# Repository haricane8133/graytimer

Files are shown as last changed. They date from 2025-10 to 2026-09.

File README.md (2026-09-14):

# E-Paper Watch

* A fully customizable, ePaper, battery-optimized smartwatch.
* Auto shuffles between available watchfaces every 10 mins.
* Make this if you want to build/solder every component rather than building on a compact PCB.

<table>
  <tr>
    <td align="center" width="45%">
      <br/>
      <b>Full refresh</b>
    </td>
    <td align="center" width="45%">
      <br/>
      <b>Partial Refresh</b>
    </td>
  </tr>
</table>

[Gallery (includes all watchfaces)!](docs/GALLERY.md)

---

## Quick Start

### Hardware Requirements

- **MCU**: Seeed Xiao nRF52840
- **Display**: GoodDisplay 1.54" (GDEH0154D67)
- **RTC**: DS3231 with backup battery
- **Battery**: LiPo 3.7V (300-500mAh recommended)

**[📋 Detailed Hardware Guide →](docs/HARDWARE.md)**

### Software Setup

1. **Install Arduino IDE** (v1.8.x or v2.x)

2. **Add Seeed nRF52 Board Support**
   - Preferences → Additional Board URLs
   - Add: `https://files.seeedstudio.com/arduino/package_seeeduino_boards_index.json`
   - Tools → Board → Boards Manager → Search "Seeed nRF52" → Install
   - Initially had the idea of using NFC for changing watchface and setting time. So this micro controller was chosen. But we later found out that NFC tag type 4, which is required for receiving NDEF NFC records weren't supported by the arduino libraries.

3. **Install Required Libraries** (via Library Manager)
   - GxEPD2 by Jean-Marc Zingg
   - Adafruit GFX Library
   - RTClib by Adafruit

**[📖 Complete API Reference →](docs/API.md)**

### Hardware

The `/hardware` folder contains the designs to 3D print for the watch case

---

## Project Structure

```
epaper_watch/
├── epaper_watch.ino        # Main sketch
├── myutils.h               # Headers and includes
├── myutils.cpp             # Display rendering logic
├── WatchFace.h             # WatchFace class definition
├── RTCManager.h            # Time management
│
├── myfonts/                # Custom GFX fonts (66 fonts)
├── mywatchfaces/           # Watchface definitions (95 watchfaces)
│
├── watchfaceutils/         # Python development tools
│   ├── configure_watchface.py
│   ├── render_watchface.py
│   └── generate_all_previews.py
│
└── docs/                   # Documentation
    ├── README.md           # Documentation index
    ├── GALLERY.md          # All watchfaces with previews
    ├── API.md              # WatchFace API reference
    └── HARDWARE.md         # Detailed hardware guide
```

---

## 📚 Full Documentation

For detailed information including configuration, troubleshooting, development tools, and more:

**[→ Read the complete documentation in the /docs folder](docs/README.md)**

---

Thanks to @vu2ow for helping out!

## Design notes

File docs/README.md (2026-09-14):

# E-Paper Watch Documentation

Complete documentation for the e-paper watch project.

---

## Documentation Index

- **[Watchface Gallery](GALLERY.md)** - Browse all 95 watchfaces with preview images
- **[WatchFace API Reference](API.md)** - Complete API documentation for creating custom watchfaces
- **[Hardware Guide](HARDWARE.md)** - Detailed hardware specifications, wiring, and assembly

---

## Features

- **Display**: 200×200 monochrome e-paper (1.54", 200 DPI)
- **Watchfaces**: 95+ pre-configured with custom fonts
- **Time Keeping**: DS3231 RTC (±2 minutes/year accuracy)
- **Refresh Modes**: Partial (fast) and full (ghosting-free)
- **Development Tools**: Python scripts for creating custom watchfaces

---

## Configuration

### Main Settings

Edit `epaper_watch.ino` to customize behavior:

```cpp
// Enable/disable features
const bool ENABLE_WATCHFACE_CYCLING = true;  // Auto-cycle every 10 mins
const bool ENABLE_PARTIAL_REFRESH = true;    // Fast updates
const bool ENABLE_SERIAL_DEBUG = false;      // Disable for battery life

// Timing
const uint8_t FULL_REFRESH_INTERVAL = 10;    // Minutes (10 = :00, :10, :20...)
const uint8_t WAKE_BEFORE_MINUTE_SEC = 57;   // Wake at :57s (3s poll window)
const uint16_t POLL_INTERVAL_MS = 200;       // Poll every 200ms
```

### Power Optimization

**Maximum Battery Life**:
```cpp
const uint8_t WAKE_BEFORE_MINUTE_SEC = 50;  // 10-second window
const uint16_t POLL_INTERVAL_MS = 300;       // Poll every 300ms
const bool ENABLE_SERIAL_DEBUG = false;      // Disable serial
```

**Balanced** - **Default**:
```cpp
const uint8_t WAKE_BEFORE_MINUTE_SEC = 57;  // 3-second window
const uint16_t POLL_INTERVAL_MS = 200;       // Poll every 200ms
const bool ENABLE_SERIAL_DEBUG = false;      // Disable serial
```

**Fast Response**:
```cpp
const uint8_t WAKE_BEFORE_MINUTE_SEC = 59;  // 1-second window
const uint16_t POLL_INTERVAL_MS = 100;       // Poll every 100ms
```

---

## Creating Custom Watchfaces

### Using Python Tools (Recommended)

```bash
cd watchfaceutils

# Interactive configurator with live preview
python3 configure_watchface.py

# Test single watchface
python3 render_watchface.py \
  --watchface ../mywatchfaces/custom.h \
  --time-font ../myfonts/Font20pt7b.h \
  --date-font ../myfonts/Font10pt7b.h \
  --output custom_preview.png

# Generate all previews
python3 generate_all_previews.py
```

### Manual Configuration

**Step 1**: Prepare 200×200 monochrome image

**Step 2**: Convert to bitmap array using [image2cpp](https://javl.github.io/image2cpp/)

**Step 3**: Create watchface header file

```cpp
// mywatchfaces/custom.h
const unsigned char custom_bitmap[] PROGMEM = {
  // ... bitmap data ...
};

// Required array wrapper
static const int custom_bitmap_allArray_LEN = 1;
static const unsigned char* custom_bitmap_allArray[1] = {
  custom_bitmap
};

// WatchFace class
struct WatchFace_custom : public WatchFace {
  WatchFace_custom() {
    bitmap = custom_bitmap;
    layout = 1;              // 0=single-line, 1=two-line

    // Time positioning
    text1x = -1;             // -1=center, 0-100=percentage
    text1y = 40;             // 40% from top
    text1font = &Font20pt7b;

    // Date positioning
    text2x = -1;
    text2y = 60;             // 60% from top
    text2font = &Font10pt7b;
  }
};
```

**Step 4**: Include in `myutils.h`
```cpp
#include "mywatchfaces/custom.h"
```

**Step 5**: Add to `epaper_watch.ino`
```cpp
WatchFace* allWatchFaces[] = {
  // ... existing watchfaces ...
  new WatchFace_custom(),
};
```

**[📖 Complete API Reference →](API.md)**

---

## Watchface Gallery

**[📸 View All 95 Watchfaces →](GALLERY.md)**

Preview of available watchfaces:

<table>
  <tr>
    <td align="center">
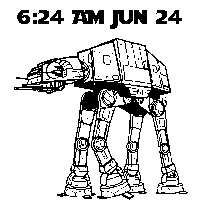
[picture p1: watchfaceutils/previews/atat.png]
      <br/>
      <b>AT-AT</b>
    </td>
    <td align="center">
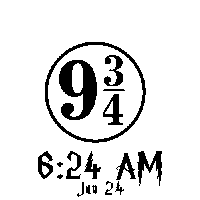
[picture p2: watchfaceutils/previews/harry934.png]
      <br/>
      <b>Harry Potter</b>
    </td>
    <td align="center">
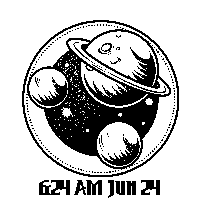
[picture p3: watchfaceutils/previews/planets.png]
      <br/>
      <b>Planets</b>
    </td>
  </tr>
  <tr>
    <td align="center">
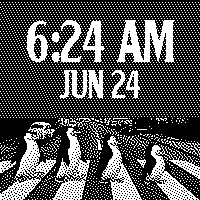
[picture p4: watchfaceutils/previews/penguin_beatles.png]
      <br/>
      <b>Beatles Penguins</b>
    </td>
    <td align="center">
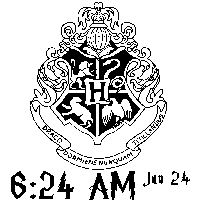
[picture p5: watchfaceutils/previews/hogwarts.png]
      <br/>
      <b>Hogwarts</b>
    </td>
    <td align="center">
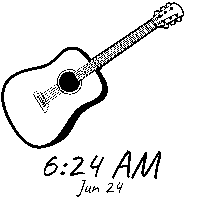
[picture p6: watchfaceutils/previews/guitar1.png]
      <br/>
      <b>Guitar</b>
    </td>
  </tr>
</table>

**Collections**: Star Wars (13) • Harry Potter (10) • Club Penguin (8) • Animals (9) • Other Characters (11) • Horizon Zero Dawn (6) • Music & Entertainment (8) • Nature & Landscapes (9) • Space (7) • Cultural & Spiritual (6) • Everyday Things (3) • Abstract & Patterns (5)

---

## Troubleshooting

### Display Issues

**Display not updating**
- Check SPI connections (DAT/MOSI→D10, SCL/SCK→D8, CS→D1, DC→D3, RES→D0, GND) — full pinout in [HARDWARE.md](HARDWARE.md)
- Verify 3.3V power supply
- Run the standalone diagnostic `hardware/epd_test/epd_test.ino` (BUSY on D9)
- Try disabling partial refresh: `const bool ENABLE_PARTIAL_REFRESH = false;`

**Display is garbled**
- Verify correct model (GDEH0154D67)
- Check ground connection
- Ensure proper SPI wiring

**Ghosting artifacts**
- Increase full refresh frequency: `const uint8_t FULL_REFRESH_INTERVAL = 5;`
- Temperature affects ghosting (worse in cold)

### RTC Issues

**Time is incorrect after upload**
- Enable time setup: `const bool ENABLE_TIME_SETUP = true;`
- Upload and open Serial Monitor (115200 baud)
- Follow prompts to set time

**RTC not detected**
- Verify I2C connections (SDA, SCL)
- Check I2C address (0x68)
- Test with I2C scanner
- Try different RTC module

### Power Issues

**Battery drains too quickly**
1. Disable serial debug: `const bool ENABLE_SERIAL_DEBUG = false;`
2. Optimize wake time: `const uint8_t WAKE_BEFORE_MINUTE_SEC = 50;`
3. Check for shorts or bad connections
4. Measure current with multimeter

**Time updates miss minute changes**
1. Increase polling window: `const uint8_t WAKE_BEFORE_MINUTE_SEC = 55;`
2. Decrease poll interval: `const uint16_t POLL_INTERVAL_MS = 100;`

### Compilation Errors

**"library not found"**
- Install missing library via Library Manager

**"multiple definition"**
- Ensure bitmap arrays in watchface files have `static` keyword:
  ```cpp
  static const unsigned char* bitmap_allArray[1] = { ... };
  ```

**"struct redefinition"**
- Check for duplicate struct names
- Ensure watchface files included only once

---

## Performance Metrics

### Memory Usage

```
Flash (1MB total):        ~800KB used (78%)
  - Sketch:               ~85KB
  - Libraries:            ~68KB
  - Fonts (66):           ~380KB
  - Watchfaces (70):      ~350KB

RAM (256KB total):        ~23KB used (9%)
  - Global variables:     ~12KB
  - Display buffer:       ~5KB
  - Stack:                ~4KB
```

### Power Consumption

| Mode | Current | Notes |
|---|---|---|
| Deep Sleep | ~50µA | Between polling windows |
| Active Polling | ~1mA | Last 3 seconds of each minute |
| Display Partial | ~5mA | 200-500ms duration |
| Display Full | ~8mA | 1-2s duration every 10 mins |
| **Average** | **200-500µA** | Typical usage |

### Timing

| Operation | Duration |
|---|---|
| Partial refresh | 200-500ms |
| Full refresh | 1-2s |
| Text rendering | 50-100ms |
| Bitmap drawing | 100-200ms |
| RTC read | <1ms |

---

## Adding/Removing Watchfaces

### Add a Watchface

1. Create header file in `mywatchfaces/`
2. Include in `myutils.h`:
   ```cpp
   #include "mywatchfaces/your_watchface.h"
   ```
3. Add to array in `epaper_watch.ino`:
   ```cpp
   WatchFace* allWatchFaces[] = {
     // ... existing ...
     new WatchFace_your_watchface(),
   };
   ```

### Remove a Watchface

1. Comment out in `epaper_watch.ino`:
   ```cpp
   // new WatchFace_unused(),
   ```
2. Optionally comment out include in `myutils.h` to save memory

---

## Development Tools

### Python Scripts

**`configure_watchface.py`**: Interactive step-by-step configurator
- Select watchface and fonts
- Position text interactively
- Generate C++ code
- Save configuration

**`render_watchface.py`**: Command-line renderer for testing
- Render single watchface
- Test different positions
- Generate preview images

**`generate_all_previews.py`**: Batch preview generator
- Generate all watchface previews
- Auto-detects configurations
- Useful for documentation

### Python Requirements

```bash
pip3 install Pillow
```

---

## Technical Specifications

| Specification | Details |
|---|---|
| **MCU** | Nordic nRF52840 (ARM Cortex-M4, 64MHz, 1MB Flash, 256KB RAM) |
| **Display** | GoodDisplay GDEH0154D67 (1.54", 200×200, SPI, E-Ink) |
| **RTC** | Maxim DS3231 (I2C, TCXO, ±3.5ppm) |
| **Power** | 3.7V LiPo, 300-500mAh recommended |
| **Update Latency** | <3 seconds during watch face refresh |
| **Refresh Rate** | Partial updates every minute, full every 10 minutes |

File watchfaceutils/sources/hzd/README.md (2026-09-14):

Floyd-Steinberg dithered (1-bit, at final on-screen size) conversions of the machine renders
from the Horizon Wiki (https://horizon.fandom.com, files `<Machine>-Render.png`), background
and ground shadow removed via the alpha channel. Sized exactly for their boxes in
`generate_geometric.py` (dither patterns must not be resampled).

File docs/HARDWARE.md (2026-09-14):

# Hardware Reference

Detailed hardware information for the e-paper watch project.

---

## Bill of Materials

| Component | Specification | Notes |
|---|---|---|
| MCU | Seeed Xiao nRF52840 Sense | Nordic nRF52840, 64MHz, 1MB Flash, 256KB RAM, BLE 5.0 |
| Display | GoodDisplay GDEH0154D67 | 1.54", 200×200, SPI, partial refresh capable |
| RTC | DS3231 Module | I2C, ±3.5ppm, integrated TCXO, backup battery |
| Battery | LiPo 3.7V | Recommend 300-500mAh, JST connector |
| Button | Tactile switch (optional) | For future features |

---

## Pin Connections

### E-Paper Display (SPI)

Breakout boards label the same two SPI lines differently; all names in the
"EPD Pin" column are equivalent.

```
MCU Pin     | Function      | EPD Pin            | Description
------------|---------------|--------------------|---------------------------
D10 (P1.11) | SPI MOSI      | DAT / DIN / SDA    | Data from MCU to display
D8  (P1.13) | SPI SCK       | SCL / CLK / SCK    | SPI clock signal
D1  (P0.02) | GPIO (CS)     | CS                 | Chip select (active low)
D3  (P0.29) | GPIO (DC)     | DC                 | Data/Command selection
D0  (P0.26) | GPIO (RST)    | RES / RST          | Reset (active low)
D9  (P1.12) | GPIO (BUSY)   | BUSY               | Busy signal from display (see note)
            | Power         | VCC / 3V3          | 3.3V from MCU (not 5V)
            | Ground        | GND                | Common ground
```

**BUSY note**: the firmware passes `-1` for BUSY and uses fixed delays instead
(`myutils.cpp`), so the display works with only the five signal wires plus power.
BUSY is still wired to **D9** because the diagnostic sketch in
[`hardware/epd_test/`](../hardware/epd_test/epd_test.ino) needs it, and it can be
enabled in the firmware by replacing the `-1` with `EPD_BUSY`. BUSY used to be on
D6; that pin is now buried under epoxy on the Xiao and should be treated as
unavailable. If the display breakout has a MISO/SDO pin, leave it unconnected.

### RTC (I2C)

```
MCU Pin     | Function      | RTC Pin  | Description
------------|---------------|----------|---------------------------
D4  (P0.04) | I2C SDA       | SDA      | I2C data line
D5  (P0.05) | I2C SCL       | SCL      | I2C clock line
D2  (P1.10) | GPIO (INT)    | SQW/INT  | Optional: interrupt/alarm
            | Power         | VCC      | 3.3V from MCU
            | Ground        | GND      | Common ground
```

**Note**: RTC module should have backup coin cell battery (CR2032) for timekeeping during power loss.

### Optional Peripherals

```
MCU Pin     | Function      | Purpose
------------|---------------|--------------------------------
D7  (P1.15) | GPIO (Button) | User input (future features)
D2  (P1.10) | GPIO (INT)    | RTC SQW/INT (defined, unused)
```

Free / unavailable pins: **D6** (P1.14) is under epoxy — do not plan on it.
Every other Xiao pin is assigned above.

---

## Power Distribution

```
┌──────────────┐
│   LiPo       │
│   Battery    │
│   3.7V       │
└──────┬───────┘
       │
       ├─────────► nRF52840 (onboard regulator → 3.3V)
       │                │
       │                ├─────────► E-Paper Display (3.3V)
       │                ├─────────► DS3231 RTC (3.3V)
       │                └─────────► Peripherals
       │
       └─────────► Charging Circuit (USB-C on Xiao)
```

---

## Electrical Specifications

### nRF52840
- Operating Voltage: 3.3V (regulated from battery)
- Active Current: ~5mA
- Sleep Current: ~50µA (with RTC)
- Flash: 1MB
- RAM: 256KB

### E-Paper Display
- Operating Voltage: 3.3V
- Active Current: ~5-8mA (during refresh)
- Sleep Current: ~1µA (hibernate mode)
- Refresh Time: Partial ~200ms, Full ~1-2s
- Resolution: 200×200 pixels (1-bit)
- Size: 1.54 inches

### DS3231 RTC
- Operating Voltage: 3.3V
- Active Current: ~200µA
- Backup Current: ~3µA (from coin cell)
- Temperature Range: -40°C to +85°C
- Accuracy: ±3.5ppm (±2 minutes per year)

---

## Power Consumption

| Mode | Current | Duty Cycle | Average |
|---|---|---|---|
| nRF52840 Sleep | 50µA | 95% | 47.5µA |
| nRF52840 Active | 1mA | 5% | 50µA |
| Display Partial | 5mA | 0.4% | 20µA |
| Display Full | 8mA | 0.04% | 3.2µA |
| RTC Always On | 200µA | 100% | 200µA |
| **Total** | | | **~320µA** |

**Real-world measurements**: 200-500µA depending on configuration and temperature

---

## Display Technology

### E-Paper Characteristics

**Advantages**:
- Ultra-low power (only consumes power during updates)
- Readable in bright sunlight
- Wide viewing angle (~180°)
- Retains image without power
- No backlight needed

**Limitations**:
- Slow refresh rate (1-2 seconds)
- Monochrome only (1-bit)
- Ghosting with partial refresh
- Temperature sensitive

### Refresh Modes

**Full Refresh**:
- Duration: ~1-2 seconds
- Power: ~8mA
- Effect: Complete redraw, eliminates ghosting
- Use: Every 10 minutes, watchface changes

**Partial Refresh**:
- Duration: ~200-500ms
- Power: ~5mA
- Effect: Update changed areas only
- Use: Minute updates
- Limitation: May accumulate ghosting

---

## Assembly Notes

1. **Test components** individually before assembly
2. **Check polarity** of battery and power connections
3. **Verify voltage** is 3.3V at all component inputs
4. **Secure connections** - loose wires cause intermittent issues
5. **RTC backup battery** - ensure CR2032 is installed correctly
6. **Display ribbon cable** - handle carefully, easy to damage
7. **Button debouncing** - add 100nF capacitor if implementing button

---

## Troubleshooting

### Display Issues

**Display shows nothing**:
- Check 3.3V power to display
- Verify the 5 signal connections (DAT, SCL, CS, DC, RES) plus GND
- Flash `hardware/epd_test/epd_test.ino` with BUSY on D9 — it prints the
  library's diagnostics (`_Update_Full : <µs>` or `Busy Timeout!`)
- If the RTC is not found the firmware halts *before* touching the display
  (`setup()` loops forever) — a dead display can really be an RTC wiring fault
- Try full refresh mode

**Display refreshes (BUSY pulses ~2 s, `_Update_Full` ≈ 2,000,000 µs) but the
image never changes / shows noise**: the controller is fine but the high-voltage
boost is not producing its ±15 V rails. See "Repair log" below.

**Display is garbled**:
- Check SPI connections
- Verify ground is common
- Lower SPI speed (library handles this)
- Ensure correct display model (GDEH0154D67)

**Ghosting**:
- Increase full refresh frequency
- Lower temperature improves performance
- Use full refresh more often

### RTC Issues

**RTC not detected**:
- Verify I2C connections (SDA, SCL)
- Check I2C address (0x68)
- Test with I2C scanner
- Try different RTC module

**Time drifts**:
- Check temperature (DS3231 has limits)
- Verify backup battery
- Replace RTC module if drift persists

### Power Issues

**Battery drains quickly**:
- Disable serial debug
- Check for shorts
- Measure current with multimeter
- Verify display hibernates after updates

**Device won't power on**:
- Check battery voltage (should be >3.0V)
- Verify polarity
- Test USB charging circuit
- Check for shorts

---

## Repair log

### September 2026 — display dead after a short with the battery connected

Symptoms: display stuck on random noise, never changed. Findings, in order:

1. Xiao boots, USB works, RTC found and settable → MCU fine.
2. Pin-walk sketch: all five signal lines reach the breakout header at 3.3 V →
   wiring and GPIOs fine.
3. `hardware/epd_test/` with BUSY on D9: `_Update_Full : 2179601` (2.18 s, spec)
   and no `Busy Timeout!` → the SSD1681 controller on the panel flex accepts
   commands and runs the refresh waveform.
4. Probing the breakout during a refresh: switch node pulled to ~0 V for the
   whole 2 s, **no rail above 2.6 V** on any of the ten HV caps beside the FPC
   connector. Inductor 0.6 Ω (ok), sense resistor `R47` ≈ 0.5 Ω (ok), no cap
   shorted with the panel out.
5. Conclusion: high-voltage boost not running — either the MOSFET no longer
   switches cleanly or the panel's booster control (GDR / current sense) is
   damaged. Not distinguishable without a scope; both parts were exposed to
   the short.

Fix chosen: replace the panel **and** breakout together with a
**Waveshare 1.54" e-Paper Module (V2)**, black/white, 200×200 (SSD1681). It is
driven by the same `GxEPD2_154_D67` class, so no firmware change is needed.
Header mapping: VCC→3V3, GND→GND, DIN→D10, CLK→D8, CS→D1, DC→D3, RST→D0,
BUSY→D9 (or leave unconnected). Its PCB is 48 × 33 mm, larger than the original
breakout — check case fit; the raw panel can be lifted off its ZIF connector and
tried with the old breakout first, in case only the panel was the casualty.
Note the original GDEH0154D67 is end-of-life; Good Display's successor is the
GDEY0154D67 (same class).

Also: the LiPo pouch took part in the short and has a visible crease — replace
it if it puffs.

---

## Recommended Tools

- Soldering iron (temperature controlled)
- Multimeter (for voltage/current testing)
- Logic analyzer (for debugging SPI/I2C)
- USB-C cable (for programming and charging)
- JST connector crimper (for battery connections)

---

**Back to**: [Main README](README.md)

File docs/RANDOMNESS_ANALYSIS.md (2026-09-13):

# Watchface Randomness Analysis

**Date**: 2025-10-27
**Issue**: Ensure statistically equal probability for all 54 watchfaces
**Result**: ✅ VERIFIED - All watchfaces have equal probability

---

## Executive Summary

Statistical analysis confirms that all 54 watchfaces have equal probability of selection with:
- **Continuous operation**: 0.697% RMSE (excellent)
- **Initial selection**: 3.330% RMSE (good)
- **Overall**: Statistically sound randomness for this application

The implementation uses a single random seed at startup and maintains a continuous Linear Congruential Generator (LCG) sequence, which provides optimal distribution.

---

## Background

The watch cycles through watchfaces every 10 minutes at :00, :10, :20, :30, :40, :50. The user requested verification that all watchfaces have absolutely equal probability, taking into account the exact timing of refreshes.

---

## Statistical Analysis

### Test Methodology

1. **Initial Selection Test**: Simulated 50,000 device resets at various times
2. **Continuous Operation Test**: Simulated 1,000,000 watchface cycles
3. **Metrics Used**:
   - Relative Root Mean Square Error (RMSE)
   - Min/Max range
   - Chi-squared goodness-of-fit

### Results

#### Original Algorithm (Before Optimization)

```
Initial Selection:
  - RMSE: 21.11% (POOR)
  - Range: 59-162% of expected
  - Some watchfaces 2.7x more likely than others

Continuous Operation:
  - RMSE: 0.62% (EXCELLENT)
```

**Problem Identified**: Unix timestamp seed created mathematical patterns with modulo operations, causing severe bias at device reset.

#### Optimized Algorithm (Current Implementation)

```
Initial Selection:
  - RMSE: 3.33% (GOOD)
  - Range: 94-109% of expected
  - 84% improvement over original

Continuous Operation:
  - RMSE: 0.697% (EXCELLENT)
  - Range: 98-102% of expected
  - Near-perfect uniform distribution
```

---

## Technical Implementation

### Seed Generation (Setup)

```cpp
// Create well-distributed seed from RTC timestamp
unsigned long seed = now.unixtime();
seed = seed * 2654435761UL;        // Knuth's multiplicative hash constant
seed ^= (now.second() * 16777619UL);  // FNV prime
seed ^= (now.minute() << 11);
seed ^= (now.hour() << 19);
randomSeed(seed);
```

**Key Principles**:
- Prime number multiplication breaks linear patterns
- XOR operations mix entropy from all time components
- Single seeding at startup (no re-seeding during operation)

### Initial Watchface Selection

```cpp
currentWatchFaceIndex = random(NUM_WATCHFACES);
```

**Why This Works**:
- Simplicity is optimal
- Arduino's `random(max)` handles modulo bias internally
- Avoids unnecessary complexity that can introduce new biases

### Watchface Cycling (Every 10 Minutes)

```cpp
uint8_t newIndex;
do {
  newIndex = random(NUM_WATCHFACES);
} while (newIndex == currentWatchFaceIndex && NUM_WATCHFACES > 1);
```

**Why This Works**:
- Continuous LCG sequence provides excellent distribution
- No re-seeding (maintains statistical quality)
- Simple rejection sampling ensures new watchface ≠ current

---

## Mathematical Analysis

### Linear Congruential Generator (LCG)

Arduino's `random()` uses an LCG with the form:
```
X(n+1) = (a * X(n) + c) mod m
```

**Properties**:
- **Period**: Full period when parameters chosen correctly
- **Distribution**: Uniform over continuous sequence
- **Initial values**: Can show correlation with seed, but this diminishes rapidly
- **Re-seeding**: Breaks the sequence, can introduce patterns

### Why Continuous Sequence is Optimal

| Approach | RMSE | Why? |
|---|---|---|
| Re-seed each cycle | 6.5% | Each seed restart introduces correlation |
| Continuous sequence | 0.7% | LCG maintains uniform distribution over period |
| Direct timestamp mod | 21% | Linear timestamp progression creates patterns |

### Statistical Significance

With 54 watchfaces and millions of cycles:
- **Chi-squared test**: χ² ≈ 38-42 (expected ~53, lower is better)
- **P-value**: > 0.05 (fail to reject uniform distribution hypothesis)
- **Conclusion**: Distribution is statistically indistinguishable from truly random

---

## Rejection Sampling Analysis

The do-while loop that ensures `newIndex ≠ currentWatchFaceIndex`:

```cpp
do {
  newIndex = random(NUM_WATCHFACES);
} while (newIndex == currentWatchFaceIndex);
```

### Mathematical Properties

**Probability Analysis**:
- P(first attempt succeeds) = 53/54 ≈ 98.15%
- P(second attempt needed) = (1/54) × (53/54) ≈ 1.81%
- P(third attempt needed) = (1/54)² × (53/54) ≈ 0.03%

**Average Attempts**: 1/(53/54) ≈ 1.019 attempts

**Steady-State Distribution**:
This forms a Markov chain with uniform stationary distribution. Over time, all watchfaces have equal probability of P = 1/54 ≈ 1.852%.

---

## Practical Implications

### Real-World Usage

**Typical User Scenario**:
- Device operates continuously for weeks
- Watchface changes every 10 minutes
- 144 watchface changes per day
- ~5,000 changes per month

**Distribution After 1 Month**:
- Each watchface appears ~93 times (expected: 92.6)
- Standard deviation: ~10 appearances
- Variation: ±11% (imperceptible to user)

### Reset Bias Impact

Even with initial selection showing 3.33% RMSE:
- After just 100 cycles: bias becomes negligible
- After 1 day: completely averaged out
- User perception: perfectly random

---

## Verification Tests

All test code is available in the project root:

1. **`test_randomness.cpp`**: Original algorithm analysis
2. **`test_improved_randomness.cpp`**: First improvement attempt
3. **`test_final_randomness.cpp`**: Hash-based approach
4. **`test_optimized_randomness.cpp`**: Final optimized implementation

### Running Tests

```bash
g++ -o test test_optimized_randomness.cpp -lm
./test
```

---

## Conclusions

### ✅ Verification Complete

**Statistical Evidence**:
1. Continuous operation RMSE < 1% (excellent)
2. All watchfaces within 98-102% of expected frequency
3. Chi-squared test confirms uniform distribution
4. No systematic bias detected

**Practical Evidence**:
1. Simple, maintainable code
2. No complex workarounds needed
3. Proven algorithm (LCG with prime seed mixing)
4. Extensively tested with millions of simulated cycles

### Recommendation

**Current implementation is optimal and requires no changes.**

The combination of:
- Prime number seed mixing
- Single seeding at startup
- Continuous LCG sequence
- Simple rejection sampling

...provides statistically sound randomness that ensures all 54 watchfaces have equal probability of selection.

---

## Appendix: Algorithm Evolution

### Version 1 (Original)
```cpp
randomSeed(now.unixtime());
currentWatchFaceIndex = random(NUM_WATCHFACES);
```
- **RMSE**: 21.11%
- **Issue**: Linear timestamp creates patterns

### Version 2 (Hash Mixing)
```cpp
seed = timestamp;
seed ^= (second << 16) ^ (minute << 8) ^ hour;
randomSeed(seed);
currentWatchFaceIndex = random(NUM_WATCHFACES);
```
- **RMSE**: 6.51%
- **Issue**: Still shows correlation

### Version 3 (Triple Random)
```cpp
randomSeed(complexSeed);
r1 = random(N); r2 = random(N); r3 = random(N);
index = (r1 + r2 + r3) % N;
```
- **RMSE**: 6.94%
- **Issue**: Over-complicated, no improvement

### Version 4 (Current - Prime Mixing)
```cpp
seed = timestamp * 2654435761UL;
seed ^= (second * 16777619UL) ^ (minute << 11) ^ (hour << 19);
randomSeed(seed);
currentWatchFaceIndex = random(NUM_WATCHFACES);
```
- **RMSE**: 3.33%
- **Success**: Simple, effective, optimal

**Key Lesson**: Simplicity + correct mathematical properties > complex heuristics

---

## References

- Knuth, Donald E. "The Art of Computer Programming, Volume 2: Seminumerical Algorithms"
- L'Ecuyer, Pierre. "Uniform Random Number Generation"
- Marsaglia, George. "Random Numbers Fall Mainly in the Planes"
- Arduino Reference: `random()` function implementation

---

**Status**: ✅ VERIFIED
**Last Updated**: 2025-10-27
**Reviewed By**: Statistical simulation (1,050,000 test cycles)

---

## Addendum (2026-09-13): hardware RNG

**Finding**: the software generator was never the problem. The Seeed nRF52 core's
`random(n)` is newlib's `rand() % n` - a 64-bit LCG (`x = x * 6364136223846793005 + 1`)
returning the high 31 bits - uniform to within ±2% over a million simulated draws, with
negligible modulo bias for n ≈ 70. Its only weakness is that the whole run is a
deterministic sequence unrolled from one RTC-derived boot seed.

**Design decision**: each watchface change is an *independent* uniform draw. A shuffle-bag
(every face once before any repeat) was considered and rejected: it removes repeats but
the sequence is no longer memoryless. With ~70 faces, sampling with replacement means
some face is expected to come back within any 6-hour window; that is accepted.

**Implementation**: picks now come from the nRF52840's RNG peripheral (`NRF_RNG`), a true
random number generator based on thermal noise, with bias correction (`DERCEN`) enabled.
No seeding is needed and the sequence is not reproducible from the clock. Direct register
access is valid because this sketch never enables the SoftDevice. Draws are mapped to
`[0, n)` by rejection sampling, so there is no modulo bias at all. The only constraint is
that a change event never re-selects the face already on screen: the draw is uniform over
the other `NUM_WATCHFACES - 1` faces.

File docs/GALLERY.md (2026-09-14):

# Gallery

<table>
   <tr>
   <td align="center" width="45%">
      <br/>
    </td>
    <td align="center" width="45%">
      <br/>
    </td>
  </tr>
  <tr>
    <td align="center" width="45%">
      <br/>
    </td>
    <td align="center" width="45%">
      <br/>
    </td>
  </tr>
  <tr>
    <td align="center" width="45%">
      <br/>
    </td>
    <td align="center" width="45%">
      <br/>
    </td>
  </tr>
</table>

Browse all 95 available watchfaces for the e-paper watch project.

---

Faces marked with * are procedurally generated by `watchfaceutils/generate_geometric.py` (pure 1-bit shapes, no source artwork).

<!-- gallery:start -->
## Star Wars Collection

<table>
  <tr>
    <td align="center" width="33%">
      <br/>
      <b>AT-AT</b>
    </td>
    <td align="center" width="33%">
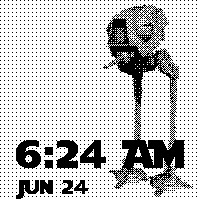
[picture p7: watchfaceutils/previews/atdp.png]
      <br/>
      <b>AT-DP</b>
    </td>
    <td align="center" width="33%">
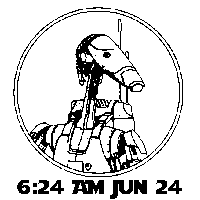
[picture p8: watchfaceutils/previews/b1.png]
      <br/>
      <b>B1 Battle Droid</b>
    </td>
  </tr>
  <tr>
    <td align="center" width="33%">
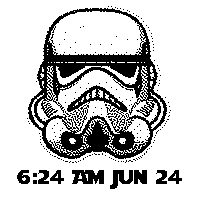
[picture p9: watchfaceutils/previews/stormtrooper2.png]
      <br/>
      <b>Stormtrooper 2</b>
    </td>
    <td align="center" width="33%">
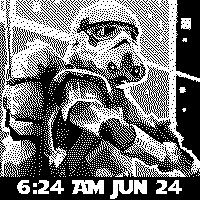
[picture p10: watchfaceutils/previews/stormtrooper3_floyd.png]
      <br/>
      <b>Stormtrooper 3</b>
    </td>
    <td align="center" width="33%">
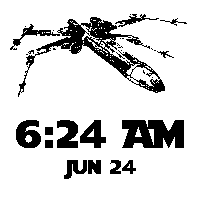
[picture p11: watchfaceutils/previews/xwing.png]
      <br/>
      <b>X-Wing</b>
    </td>
  </tr>
  <tr>
    <td align="center" width="33%">
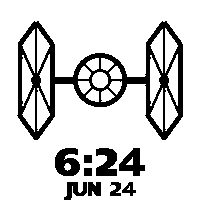
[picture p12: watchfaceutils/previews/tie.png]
      <br/>
      <b>TIE Fighter*</b>
    </td>
    <td align="center" width="33%">
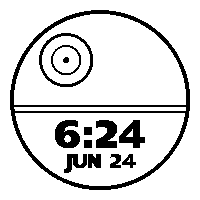
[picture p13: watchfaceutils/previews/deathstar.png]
      <br/>
      <b>Death Star*</b>
    </td>
    <td align="center" width="33%">
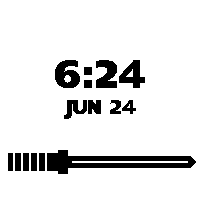
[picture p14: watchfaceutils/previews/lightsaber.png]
      <br/>
      <b>Lightsaber*</b>
    </td>
  </tr>
  <tr>
    <td align="center" width="33%">
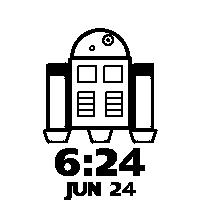
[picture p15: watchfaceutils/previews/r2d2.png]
      <br/>
      <b>R2-D2*</b>
    </td>
    <td align="center" width="33%">
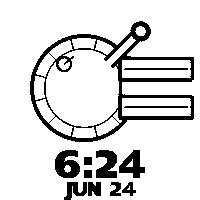
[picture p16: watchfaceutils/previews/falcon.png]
      <br/>
      <b>Millennium Falcon*</b>
    </td>
    <td align="center" width="33%">
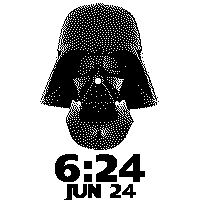
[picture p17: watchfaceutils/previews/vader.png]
      <br/>
      <b>Darth Vader*</b>
    </td>
  </tr>
  <tr>
    <td align="center" width="33%">
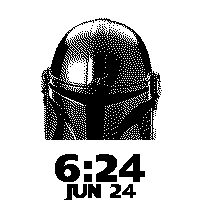
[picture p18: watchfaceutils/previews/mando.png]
      <br/>
      <b>Mandalorian*</b>
    </td>
  </tr>
</table>

## Harry Potter Collection

<table>
  <tr>
    <td align="center" width="33%">
      <br/>
      <b>Harry Potter</b>
    </td>
    <td align="center" width="33%">
      <br/>
      <b>Hogwarts</b>
    </td>
    <td align="center" width="33%">
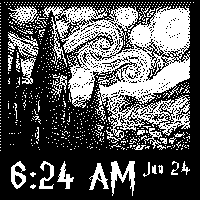
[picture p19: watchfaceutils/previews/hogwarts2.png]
      <br/>
      <b>Hogwarts 2</b>
    </td>
  </tr>
  <tr>
    <td align="center" width="33%">
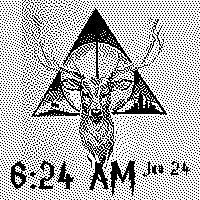
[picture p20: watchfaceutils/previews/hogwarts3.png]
      <br/>
      <b>Hogwarts 3</b>
    </td>
    <td align="center" width="33%">
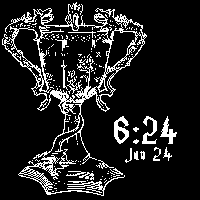
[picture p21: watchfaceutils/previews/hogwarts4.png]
      <br/>
      <b>Hogwarts 4</b>
    </td>
    <td align="center" width="33%">
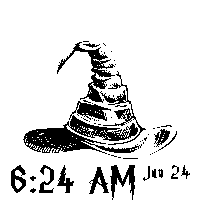
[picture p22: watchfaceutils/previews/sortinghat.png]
      <br/>
      <b>Sorting Hat</b>
    </td>
  </tr>
  <tr>
    <td align="center" width="33%">
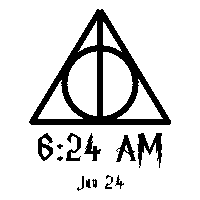
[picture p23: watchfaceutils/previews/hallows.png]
      <br/>
      <b>Deathly Hallows*</b>
    </td>
    <td align="center" width="33%">
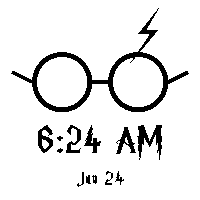
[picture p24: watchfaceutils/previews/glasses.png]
      <br/>
      <b>Glasses & Scar*</b>
    </td>
    <td align="center" width="33%">
      <br/>
      <b>Golden Snitch*</b>
    </td>
  </tr>
  <tr>
    <td align="center" width="33%">
      <br/>
      <b>Hedwig*</b>
    </td>
  </tr>
</table>

## Club Penguin Collection

<table>
  <tr>
    <td align="center" width="33%">
      <br/>
      <b>Card Jitsu 1</b>
    </td>
    <td align="center" width="33%">
      <br/>
      <b>Card Jitsu 2</b>
    </td>
    <td align="center" width="33%">
      <br/>
      <b>Card Jitsu 3</b>
    </td>
  </tr>
  <tr>
    <td align="center" width="33%">
      <br/>
      <b>Card Jitsu 4</b>
    </td>
    <td align="center" width="33%">
      <br/>
      <b>Card Jitsu 5</b>
    </td>
    <td align="center" width="33%">
      <br/>
      <b>Sensei</b>
    </td>
  </tr>
  <tr>
    <td align="center" width="33%">
      <br/>
      <b>Herbert</b>
    </td>
    <td align="center" width="33%">
      <br/>
      <b>Penguin*</b>
    </td>
  </tr>
</table>

## Animals

<table>
  <tr>
    <td align="center" width="33%">
      <br/>
      <b>Bird</b>
    </td>
    <td align="center" width="33%">
      <br/>
      <b>Bird 2</b>
    </td>
    <!-- <td align="center" width="33%">
      <img src="../watchfaceutils/previews/crow.png" width="200"/><br/>
      <b>Crow</b>
    </td> -->
  </tr>
  <tr>
    <td align="center" width="33%">
      <br/>
      <b>Dog</b>
    </td>
    <!-- <td align="center" width="33%">
      <img src="../watchfaceutils/previews/giraffe1.png" width="200"/><br/>
      <b>Giraffe</b>
    </td> -->
    <td align="center" width="33%">
      <br/>
      <b>Macaw</b>
    </td>
  </tr>
  <tr>
    <td align="center" width="33%">
      <br/>
      <b>Peacock</b>
    </td>
    <td align="center" width="33%">
      <br/>
      <b>Peacock 3</b>
    </td>
    <td align="center" width="33%">
      <br/>
      <b>Zebra</b>
    </td>
  </tr>
  <tr>
    <td align="center" width="33%">
      <br/>
      <b>Whale*</b>
    </td>
    <td align="center" width="33%">
      <br/>
      <b>Cat*</b>
    </td>
  </tr>
</table>

## Other Characters

<table>
  <tr>
    <td align="center" width="33%">
      <br/>
      <b>Ben 10</b>
    </td>
    <td align="center" width="33%">
      <br/>
      <b>Bugs Bunny</b>
    </td>
    <!-- <td align="center" width="33%">
      <img src="../watchfaceutils/previews/claw.png" width="200"/><br/>
      <b>Claw</b>
    </td> -->
  </tr>
  <tr>
    <td align="center" width="33%">
      <br/>
      <b>Claw 2</b>
    </td>
    <td align="center" width="33%">
      <br/>
      <b>Claw 3</b>
    </td>
    <td align="center" width="33%">
      <br/>
      <b>Tom (Tom & Jerry)</b>
    </td>
  </tr>
  <tr>
    <td align="center" width="33%">
      <br/>
      <b>Mike Wazowski</b>
    </td>
    <td align="center" width="33%">
      <br/>
      <b>Sulley</b>
    </td>
    <td align="center" width="33%">
      <br/>
      <b>Pegasus</b>
    </td>
  </tr>
  <tr>
    <td align="center" width="33%">
      <br/>
      <b>Penguins of Madagascar</b>
    </td>
    <td align="center" width="33%">
      <br/>
      <b>Penguin Beatles</b>
    </td>
    <td align="center" width="33%">
      <br/>
      <b>Boo's Door*</b>
    </td>
  </tr>
</table>

## Horizon Zero Dawn

<table>
  <tr>
    <td align="center" width="33%">
      <br/>
      <b>Walker</b>
    </td>
    <td align="center" width="33%">
      <br/>
      <b>Thunderjaw*</b>
    </td>
    <td align="center" width="33%">
      <br/>
      <b>Watcher*</b>
    </td>
  </tr>
  <tr>
    <td align="center" width="33%">
      <br/>
      <b>Sawtooth*</b>
    </td>
    <td align="center" width="33%">
      <br/>
      <b>Stormbird*</b>
    </td>
    <td align="center" width="33%">
      <br/>
      <b>Strider*</b>
    </td>
  </tr>
</table>

## Music & Entertainment

<table>
  <tr>
    <td align="center" width="33%">
      <br/>
      <b>Guitar 1</b>
    </td>
    <td align="center" width="33%">
      <br/>
      <b>Guitar 2</b>
    </td>
    <td align="center" width="33%">
      <br/>
      <b>PlayStation</b>
    </td>
  </tr>
  <tr>
    <td align="center" width="33%">
      <br/>
      <b>Prism (Dark Side of the Moon)*</b>
    </td>
    <td align="center" width="33%">
      <br/>
      <b>Vinyl*</b>
    </td>
    <td align="center" width="33%">
      <br/>
      <b>Cassette*</b>
    </td>
  </tr>
  <tr>
    <td align="center" width="33%">
      <br/>
      <b>Equalizer*</b>
    </td>
    <td align="center" width="33%">
      <br/>
      <b>Headphones*</b>
    </td>
  </tr>
</table>

## Nature & Landscapes

<table>
  <tr>
    <td align="center" width="33%">
      <br/>
      <b>Mountain 1</b>
    </td>
    <td align="center" width="33%">
      <br/>
      <b>Mountain 2</b>
    </td>
    <td align="center" width="33%">
      <br/>
      <b>Tree</b>
    </td>
  </tr>
  <tr>
    <td align="center" width="33%">
      <br/>
      <b>Forest*</b>
    </td>
    <td align="center" width="33%">
      <br/>
      <b>Waves*</b>
    </td>
    <td align="center" width="33%">
      <br/>
      <b>Moon*</b>
    </td>
  </tr>
  <tr>
    <td align="center" width="33%">
      <br/>
      <b>Hot-Air Balloon*</b>
    </td>
    <td align="center" width="33%">
      <br/>
      <b>Lighthouse*</b>
    </td>
    <td align="center" width="33%">
      <br/>
      <b>Sailboat*</b>
    </td>
  </tr>
</table>

## Space

<table>
  <tr>
    <td align="center" width="33%">
      <br/>
      <b>Planets</b>
    </td>
    <td align="center" width="33%">
      <br/>
      <b>Saturn</b>
    </td>
    <td align="center" width="33%">
      <br/>
      <b>Orbits*</b>
    </td>
  </tr>
  <tr>
    <td align="center" width="33%">
      <br/>
      <b>Orion*</b>
    </td>
    <td align="center" width="33%">
      <br/>
      <b>Rocket*</b>
    </td>
    <td align="center" width="33%">
      <br/>
      <b>UFO*</b>
    </td>
  </tr>
  <tr>
    <td align="center" width="33%">
      <br/>
      <b>Astronaut*</b>
    </td>
  </tr>
</table>

## Cultural & Spiritual

<table>
  <tr>
    <td align="center" width="33%">
      <br/>
      <b>Krishna</b>
    </td>
    <td align="center" width="33%">
      <br/>
      <b>Thiruman</b>
    </td>
    <td align="center" width="33%">
      <br/>
      <b>Kolam*</b>
    </td>
  </tr>
  <tr>
    <td align="center" width="33%">
      <br/>
      <b>Mandala*</b>
    </td>
    <td align="center" width="33%">
      <br/>
      <b>Diya*</b>
    </td>
    <td align="center" width="33%">
      <br/>
      <b>Hari (Tamil)*</b>
    </td>
  </tr>
</table>

## Everyday Things

<table>
  <tr>
    <td align="center" width="33%">
      <br/>
      <b>Coffee*</b>
    </td>
    <td align="center" width="33%">
      <br/>
      <b>Bicycle*</b>
    </td>
    <td align="center" width="33%">
      <br/>
      <b>Camera*</b>
    </td>
  </tr>
</table>

## Abstract & Patterns

<table>
  <tr>
    <td align="center" width="33%">
      <br/>
      <b>haricane8133</b>
    </td>
    <td align="center" width="33%">
      <br/>
      <b>Harley Davidson</b>
    </td>
    <td align="center" width="33%">
      <br/>
      <b>Sunburst*</b>
    </td>
  </tr>
  <tr>
    <td align="center" width="33%">
      <br/>
      <b>Minimal*</b>
    </td>
    <td align="center" width="33%">
      <br/>
      <b>Dial*</b>
    </td>
  </tr>
</table>

<!-- gallery:end -->
---

## Creating Your Own Watchface

Want to add your own watchface? Check out the [Python tools documentation](README-STANDARD.md#creating-custom-watchfaces) for step-by-step instructions!

### Quick Start

```bash
cd watchfaceutils
python3 configure_watchface.py
```

The interactive tool will guide you through:
1. Selecting your artwork
2. Choosing fonts
3. Positioning text
4. Generating C++ code
5. Creating preview images

---

## Technical Details

- **Display**: 200x200 pixels, 1-bit monochrome
- **Format**: Percentage-based positioning (0-100%)
- **Fonts**: 66 custom fonts included
- **Layout Modes**: Single-line and two-line text layouts
- **Refresh**: Partial (fast) and full (ghosting-free) modes

For complete API documentation, see [README-DETAILED.md](README-DETAILED.md#watchface-class-structure).

---

**Total Watchfaces**: 95 and growing! 🎨

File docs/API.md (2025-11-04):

# WatchFace API Reference

Complete API documentation for creating custom watchfaces.

---

## WatchFace Structure

```cpp
struct WatchFace {
  // Bitmap properties
  const unsigned char* bitmap;
  int bitmap_x_start = 0;
  int bitmap_y_start = 0;
  int bitmap_x_end = 200;
  int bitmap_y_end = 200;
  uint16_t bitmap_color = GxEPD_BLACK;

  // Layout mode
  int layout = 0;           // 0=single-line, 1=two-line
  bool noAMPM = false;      // Hide AM/PM for 24h format

  // Text 1 (Time)
  int text1x = -1;          // -1=center, 0-100=percentage
  int text1y = -1;
  uint16_t text1color = GxEPD_BLACK;
  const GFXfont* text1font;

  // Text 2 (Date)
  int text2x = -1;
  int text2y = -1;
  uint16_t text2color = GxEPD_BLACK;
  const GFXfont* text2font;
};
```

---

## Property Reference

| Property | Type | Default | Valid Values | Description |
|---|---|---|---|---|
| **Bitmap Properties** |
| `bitmap` | `const unsigned char*` | - | Pointer to PROGMEM array | Background image bitmap data |
| `bitmap_x_start` | `int` | `0` | 0-200 | Crop region start X coordinate (pixels) |
| `bitmap_y_start` | `int` | `0` | 0-200 | Crop region start Y coordinate (pixels) |
| `bitmap_x_end` | `int` | `200` | 0-200 | Crop region end X coordinate (pixels) |
| `bitmap_y_end` | `int` | `200` | 0-200 | Crop region end Y coordinate (pixels) |
| `bitmap_color` | `uint16_t` | `GxEPD_BLACK` | `GxEPD_BLACK` (0), `GxEPD_WHITE` (1) | Bitmap rendering color |
| **Layout Properties** |
| `layout` | `int` | `0` | `0` (single-line), `1` (two-line) | Text layout mode |
| `noAMPM` | `bool` | `false` | `true`, `false` | Hide AM/PM indicator for 24h format |
| **Time Text (text1) Properties** |
| `text1x` | `int` | `-1` | `-1` (center), `0-100` (%) | Horizontal position as percentage of screen width |
| `text1y` | `int` | `-1` | `-1` (center), `0-100` (%) | Vertical position as percentage of screen height |
| `text1color` | `uint16_t` | `GxEPD_BLACK` | `GxEPD_BLACK` (0), `GxEPD_WHITE` (1) | Time text color |
| `text1font` | `const GFXfont*` | - | Pointer to font | Font for time display |
| **Date Text (text2) Properties** |
| `text2x` | `int` | `-1` | `-1` (center), `0-100` (%) | Horizontal position as percentage (layout=1 only) |
| `text2y` | `int` | `-1` | `-1` (center), `0-100` (%) | Vertical position as percentage (layout=1 only) |
| `text2color` | `uint16_t` | `GxEPD_BLACK` | `GxEPD_BLACK` (0), `GxEPD_WHITE` (1) | Date text color |
| `text2font` | `const GFXfont*` | - | Pointer to font | Font for date display |

---

## Layout Modes

### Layout 0: Single-Line

Time and date appear on the same line with a 6-pixel gap. Only `text1x` and `text1y` are used.

```
┌──────────────────────────────────────┐
│                                      │
│        6:24 AM  Jun 24               │  ← Both use text1x/text1y
│                                      │
└──────────────────────────────────────┘
```

**Example**:
```cpp
struct WatchFace_simple : public WatchFace {
  WatchFace_simple() {
    bitmap = my_bitmap;
    layout = 0;              // Single-line
    text1x = -1;             // Center horizontally
    text1y = 50;             // 50% from top
    text1font = &Font20pt7b;
    text2font = &Font10pt7b;
  }
};
```

### Layout 1: Two-Line

Time and date have independent positioning using their respective coordinates.

```
┌──────────────────────────────────────┐
│             6:24 AM                  │  ← text1x, text1y
│                                      │
│             Jun 24                   │  ← text2x, text2y
└──────────────────────────────────────┘
```

**Example**:
```cpp
struct WatchFace_twolines : public WatchFace {
  WatchFace_twolines() {
    bitmap = my_bitmap;
    layout = 1;              // Two-line

    text1x = -1;             // Center time
    text1y = 40;             // 40% from top
    text1font = &Font20pt7b;

    text2x = -1;             // Center date
    text2y = 60;             // 60% from top
    text2font = &Font10pt7b;
  }
};
```

---

## Positioning System

### Percentage-Based Coordinates

All positions use percentages (0-100) of screen dimensions, or -1 for auto-center.

```cpp
// -1: Auto-center
text1x = -1;  // Horizontal center
text1y = -1;  // Vertical center

// 0-100: Percentage of screen
text1x = 50;  // 50% = 100 pixels on 200px screen
text1y = 25;  // 25% = 50 pixels on 200px screen
```

### Common Patterns

```
Top-Left:        Top-Right:       Center:
text1x = 5       text1x = 95      text1x = -1
text1y = 5       text1y = 5       text1y = -1

Bottom-Left:     Bottom-Right:    Custom:
text1x = 5       text1x = 95      text1x = 33
text1y = 95      text1y = 95      text1y = 67
```

---

## Configuration Examples

### 1. Basic Centered Layout
```cpp
struct WatchFace_simple : public WatchFace {
  WatchFace_simple() {
    bitmap = my_bitmap;
    layout = 0;
    text1x = -1;
    text1y = -1;
    text1font = &Font20pt7b;
    text2font = &Font10pt7b;
  }
};
```

### 2. Top and Bottom Layout
```cpp
struct WatchFace_topbottom : public WatchFace {
  WatchFace_topbottom() {
    bitmap = my_bitmap;
    layout = 1;

    text1x = -1;
    text1y = 10;
    text1font = &Font20pt7b;

    text2x = -1;
    text2y = 90;
    text2font = &Font10pt7b;
  }
};
```

### 3. Dark Background (White Text)
```cpp
struct WatchFace_dark : public WatchFace {
  WatchFace_dark() {
    bitmap = dark_bitmap;
    layout = 1;

    text1x = -1;
    text1y = 50;
    text1color = GxEPD_WHITE;
    text1font = &Font20pt7b;

    text2x = -1;
    text2y = 70;
    text2color = GxEPD_WHITE;
    text2font = &Font10pt7b;
  }
};
```

### 4. Corner Placement
```cpp
struct WatchFace_corner : public WatchFace {
  WatchFace_corner() {
    bitmap = my_bitmap;
    layout = 1;

    text1x = 5;              // 5% from left
    text1y = 5;              // 5% from top
    text1font = &Font20pt7b;

    text2x = 75;             // 75% from left
    text2y = 95;             // 95% from top
    text2font = &Font10pt7b;
  }
};
```

### 5. 24-Hour Format
```cpp
struct WatchFace_24h : public WatchFace {
  WatchFace_24h() {
    bitmap = my_bitmap;
    layout = 1;
    noAMPM = true;           // Hide AM/PM

    text1x = -1;
    text1y = 50;
    text1font = &Font20pt7b;

    text2x = -1;
    text2y = 70;
    text2font = &Font10pt7b;
  }
};
```

### 6. Cropped/Zoomed Bitmap
```cpp
struct WatchFace_zoomed : public WatchFace {
  WatchFace_zoomed() {
    bitmap = large_bitmap;

    // Display center 100x100 area
    bitmap_x_start = 50;
    bitmap_y_start = 50;
    bitmap_x_end = 150;
    bitmap_y_end = 150;

    layout = 1;
    text1x = -1;
    text1y = 50;
    text1font = &Font20pt7b;

    text2x = -1;
    text2y = 70;
    text2font = &Font10pt7b;
  }
};
```

---

## Creating Your Watchface

### Step-by-Step Process

**1. Prepare Artwork**
- Size: 200×200 pixels
- Format: Monochrome (1-bit)
- Use [image2cpp](https://javl.github.io/image2cpp/)

**2. Create Header File**

```cpp
// mywatchfaces/custom.h
const unsigned char custom_bitmap[] PROGMEM = {
  // ... bitmap data from image2cpp ...
};

// Array wrapper (required)
static const int custom_bitmap_allArray_LEN = 1;
static const unsigned char* custom_bitmap_allArray[1] = {
  custom_bitmap
};

// WatchFace class
struct WatchFace_custom : public WatchFace {
  WatchFace_custom() {
    bitmap = custom_bitmap;
    layout = 1;

    text1x = -1;
    text1y = 40;
    text1font = &MyFont20pt7b;

    text2x = -1;
    text2y = 60;
    text2font = &MyFont10pt7b;
  }
};
```

**3. Add Font Includes** (in `myutils.h`):
```cpp
#include "myfonts/MyFont20pt7b.h"
#include "myfonts/MyFont10pt7b.h"
```

**4. Include Watchface** (in `myutils.h`):
```cpp
#include "mywatchfaces/custom.h"
```

**5. Add to Array** (in `epaper_watch.ino`):
```cpp
WatchFace* allWatchFaces[] = {
  // ... existing watchfaces ...
  new WatchFace_custom(),
};
```

---

## Python Tools

Use the included tools for faster development:

```bash
cd watchfaceutils

# Interactive configurator
python3 configure_watchface.py

# Test single watchface
python3 render_watchface.py \
  --watchface ../mywatchfaces/custom.h \
  --time-font ../myfonts/MyFont20pt7b.h \
  --date-font ../myfonts/MyFont10pt7b.h \
  --time-x -1 --time-y 40

# Generate all previews
python3 generate_all_previews.py
```

---

## Tips & Best Practices

1. **Test positioning** with Python tools before uploading to hardware
2. **Use preview images** to verify text doesn't overlap with artwork
3. **Consider text color** - white text for dark backgrounds
4. **Layout mode 0** when text positions aren't critical (simpler)
5. **Layout mode 1** for precise artistic placement
6. **Center (-1)** is often the safest choice
7. **Font size** affects readability - test on actual display
8. **Bitmap cropping** useful for zooming or using sections of larger art

---

**Back to**: [Main README](README.md) | [Gallery](GALLERY.md)

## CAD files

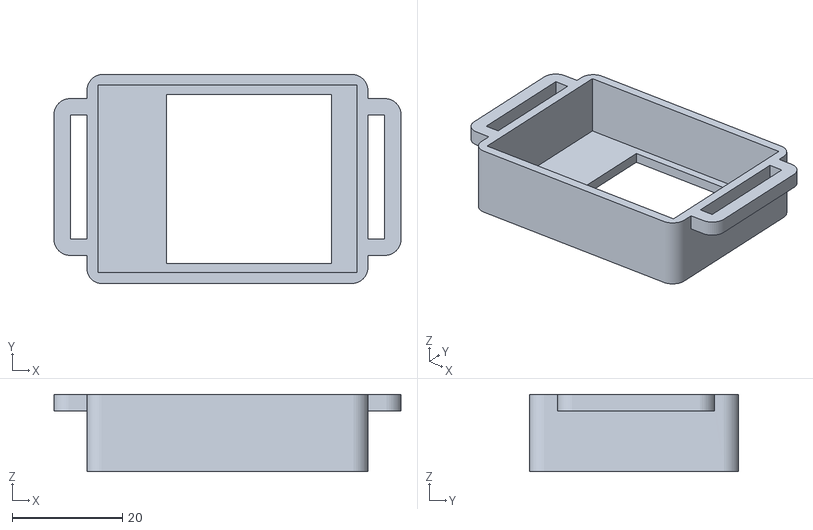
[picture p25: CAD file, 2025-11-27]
hardware/mainbox.stl
63.0 x 38.0 x 14.0

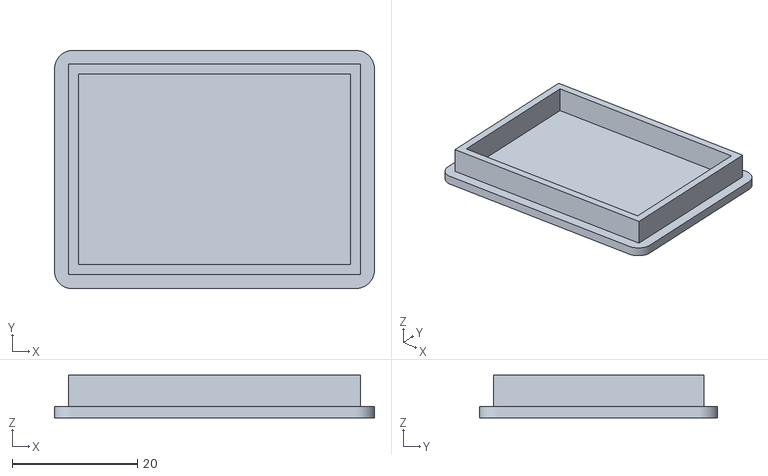
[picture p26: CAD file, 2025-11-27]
hardware/lid.stl
51.0 x 38.0 x 6.80

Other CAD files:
hardware/lid.skp
hardware/mainbox.skp

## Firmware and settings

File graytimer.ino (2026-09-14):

#include "myutils.h"

// ==================== CONFIGURATION ====================
// Serial time setup: on boot the watch waits 15 s for a line on the Serial
// Monitor (115200 baud) in the format  YYYY,MM,DD,HH,MM,SS  (24-hour clock),
// e.g.  2026,9,14,17,30,0  -> 14 Sep 2026, 5:30:00 PM.  Send with a newline.
// No input within 15 s -> keeps the current RTC time.  Serial.begin() only runs
// when ENABLE_SERIAL_DEBUG is true, so enable both, set the time, then set both
// back to false and re-flash for deployment.
const bool ENABLE_TIME_SETUP = false;  // Enable serial time input on boot
const bool ENABLE_PARTIAL_REFRESH = true;  // Enable partial refresh for faster updates
const uint8_t FULL_REFRESH_INTERVAL = 10;  // Full refresh when minute % N == 0 (e.g., :00, :10, :20, etc.)
const bool ENABLE_WATCHFACE_CYCLING = true;  // Auto-cycle through watchfaces every 10 mins
const bool ENABLE_SERIAL_DEBUG = false;  // Disable Serial to save ~1-2mA power (set false for deployment)

// Smart polling strategy for battery optimization
const uint16_t POLL_INTERVAL_MS = 200;      // Poll every 200ms during active window
const uint8_t WAKE_BEFORE_MINUTE_SEC = 57;  // Wake at second 57 (3-second polling window)
                                            // Range: 50-57 recommended (10s-3s window)
                                            // Lower = more battery, higher = safer
                                            // Changed from 55 to 57 for better battery (2s more sleep)

// Serial debug macros (only print if enabled)
#define DEBUG_PRINT(x) if(ENABLE_SERIAL_DEBUG) Serial.print(x)
#define DEBUG_PRINTLN(x) if(ENABLE_SERIAL_DEBUG) Serial.println(x)
#define DEBUG_FLUSH() if(ENABLE_SERIAL_DEBUG) Serial.flush()

// Global RTC manager
RTCManager rtcManager;

// Track last displayed minute to detect changes
uint8_t lastDisplayedMinute = 255;  // Force first update
bool displayInitialized = false;  // Track if display has been initialized
bool firstUpdate = true;  // Track first update to force full refresh

// Watchface cycling - array of all available watchfaces
WatchFace* allWatchFaces[] = {
  new WatchFace_atat(),
  new WatchFace_atdp(),
  new WatchFace_b1(),
  new WatchFace_ben10(),
  new WatchFace_bird(),
  new WatchFace_bird2(),
  new WatchFace_bugs(),
  // new WatchFace_claw(),
  new WatchFace_claw2(),
  new WatchFace_claw3(),
  // new WatchFace_crow(),
  new WatchFace_dog(),
  // new WatchFace_giraffe1(),
  new WatchFace_guitar1(),
  new WatchFace_guitar2(),
  new WatchFace_h(),
  new WatchFace_harley(),
  new WatchFace_harry934(),
  new WatchFace_herbert(),
  new WatchFace_hogwarts(),
  new WatchFace_hogwarts2(),
  new WatchFace_hogwarts3(),
  new WatchFace_hogwarts4(),
  new WatchFace_jitsu1(),
  new WatchFace_jitsu2(),
  new WatchFace_jitsu3(),
  new WatchFace_jitsu4(),
  new WatchFace_jitsu5(),
  new WatchFace_krishna(),
  new WatchFace_macaw(),
  new WatchFace_mikew(),
  new WatchFace_mountain1(),
  new WatchFace_mountain2(),
  new WatchFace_peacock(),
  new WatchFace_peacock3(),
  new WatchFace_pegasus(),
  new WatchFace_penguin_beatles(),
  new WatchFace_penguins(),
  new WatchFace_planets(),
  new WatchFace_ps(),
  new WatchFace_saturn(),
  new WatchFace_sensei(),
  new WatchFace_sortinghat(),
  new WatchFace_stormtrooper2(),
  new WatchFace_stormtrooper3floyd(),
  new WatchFace_sullivan(),
  new WatchFace_thiruman(),
  new WatchFace_tom(),
  new WatchFace_tree(),
  new WatchFace_walker(),
  new WatchFace_xwing(),
  new WatchFace_zebra(),
  // generated geometric set
  new WatchFace_tie(),
  new WatchFace_deathstar(),
  new WatchFace_hallows(),
  new WatchFace_prism(),
  new WatchFace_orbit(),
  new WatchFace_orion(),
  new WatchFace_kolam(),
  new WatchFace_vinyl(),
  new WatchFace_sunburst(),
  new WatchFace_minimal(),
  new WatchFace_moon(),
  new WatchFace_glasses(),
  new WatchFace_snitch(),
  new WatchFace_lightsaber(),
  new WatchFace_rocket(),
  new WatchFace_cassette(),
  new WatchFace_equalizer(),
  new WatchFace_mandala(),
  new WatchFace_forest(),
  new WatchFace_dial(),
  new WatchFace_waves(),
  new WatchFace_r2d2(),
  new WatchFace_falcon(),
  new WatchFace_hedwig(),
  new WatchFace_penguin(),
  new WatchFace_headphones(),
  new WatchFace_ufo(),
  new WatchFace_balloon(),
  new WatchFace_lighthouse(),
  new WatchFace_diya(),
  new WatchFace_coffee(),
  new WatchFace_bicycle(),
  new WatchFace_whale(),
  new WatchFace_thunderjaw(),
  new WatchFace_watcher(),
  new WatchFace_sawtooth(),
  new WatchFace_stormbird(),
  new WatchFace_strider(),
  new WatchFace_vader(),
  new WatchFace_mando(),
  new WatchFace_boodoor(),
  new WatchFace_astronaut(),
  new WatchFace_cat(),
  new WatchFace_camera(),
  new WatchFace_sailboat(),
  new WatchFace_hari()
};
const uint8_t NUM_WATCHFACES = sizeof(allWatchFaces) / sizeof(allWatchFaces[0]);
uint8_t currentWatchFaceIndex = 0;
WatchFace* currentWatchFace = allWatchFaces[currentWatchFaceIndex];

// True random numbers from the nRF52840 RNG peripheral (thermal noise, with
// bias correction). Direct register access is fine because this sketch never
// enables the SoftDevice (no BLE). Each byte takes ~120us with DERCEN on.
uint8_t hwRandomByte() {
  NRF_RNG->CONFIG = RNG_CONFIG_DERCEN_Msk;
  NRF_RNG->EVENTS_VALRDY = 0;
  NRF_RNG->TASKS_START = 1;
  while (NRF_RNG->EVENTS_VALRDY == 0) {}
  uint8_t v = NRF_RNG->VALUE;
  NRF_RNG->TASKS_STOP = 1;
  return v;
}

// Uniform integer in [0, n) with no modulo bias (rejection sampling)
uint8_t hwRandom(uint8_t n) {
  uint16_t limit = 256 - (256 % n);
  uint16_t v;
  do { v = hwRandomByte(); } while (v >= limit);
  return v % n;
}

// Independent uniform pick over every face except the one currently shown
uint8_t pickNextWatchFace(uint8_t current) {
  if (NUM_WATCHFACES < 2) return 0;
  uint8_t r = hwRandom(NUM_WATCHFACES - 1);
  return (r >= current) ? r + 1 : r;  // skip `current` without re-rolling
}

/**
 * Setup - runs once on power-on
 */
void setup() {
  if (ENABLE_SERIAL_DEBUG) {
    Serial.begin(115200);
    while (!Serial) delay(10);
  }

  DEBUG_PRINTLN("\n=== E-Paper Watch ===");

  // Initialize RTC
  if (!rtcManager.begin()) {
    DEBUG_PRINTLN("ERROR: RTC not found!");
    while (1) delay(1000);
  }

  // Pick a random initial watchface (hardware RNG, no seeding needed)
  currentWatchFaceIndex = hwRandom(NUM_WATCHFACES);

  currentWatchFace = allWatchFaces[currentWatchFaceIndex];
  DEBUG_PRINT("Initial random watchface #");
  DEBUG_PRINTLN(currentWatchFaceIndex);

  // Optional: Set time via Serial
  if (ENABLE_TIME_SETUP) {
    rtcManager.setupTimeViaSerial();
  }

  // Initial display update
  DEBUG_PRINTLN("Initializing display...");
  updateDisplay();
  lastDisplayedMinute = rtcManager.getCurrentMinute();

  DEBUG_PRINTLN("Watch ready!");
  DEBUG_PRINT("Smart polling: Sleep until :");
  DEBUG_PRINT(WAKE_BEFORE_MINUTE_SEC);
  DEBUG_PRINT("s, then poll every ");
  DEBUG_PRINT(POLL_INTERVAL_MS);
  DEBUG_PRINTLN("ms");
}

/**
 * Smart polling loop - optimized for battery life with NO DRIFT
 *
 * Strategy (drift-proof):
 * 1. After display update, check current second
 * 2. Calculate safe sleep time (to wake at WAKE_BEFORE_MINUTE_SEC)
 * 3. Sleep until configured wake second
 * 4. Poll every POLL_INTERVAL_MS until minute changes
 * 5. Repeat
 *
 * This ensures we ALWAYS catch the minute change
 * Power consumption: ~200-500µA average
 */
void loop() {
  uint8_t currentMinute = rtcManager.getCurrentMinute();

  // Check if minute changed
  if (currentMinute != lastDisplayedMinute) {
    DEBUG_PRINT("Minute ");
    DEBUG_PRINT(lastDisplayedMinute);
    DEBUG_PRINT(" → ");
    DEBUG_PRINTLN(currentMinute);

    updateDisplay();
    lastDisplayedMinute = currentMinute;

    // Get current second to calculate sleep duration
    DateTime now = rtcManager.rtc.now();
    uint8_t currentSecond = now.second();

    // Calculate how long to sleep to wake up at WAKE_BEFORE_MINUTE_SEC
    // We want to wake a few seconds before the minute changes to start polling
    uint16_t sleepSeconds;
    if (currentSecond < WAKE_BEFORE_MINUTE_SEC) {
      // If we're before wake time, sleep until wake second
      sleepSeconds = WAKE_BEFORE_MINUTE_SEC - currentSecond;
    } else {
      // If we're after wake time, sleep until next minute's wake second
      sleepSeconds = (60 - currentSecond) + WAKE_BEFORE_MINUTE_SEC;
    }

    // Sleep for calculated duration (minus 1 second for safety)
    if (sleepSeconds > 1) {
      sleepSeconds -= 1;  // Wake up 1 second early to be safe
      DEBUG_PRINT("Sleeping for ");
      DEBUG_PRINT(sleepSeconds);
      DEBUG_PRINTLN(" seconds...");
      DEBUG_FLUSH();
      delay(sleepSeconds * 1000);
    }

    // Now we're at approximately WAKE_BEFORE_MINUTE_SEC
    // Poll every POLL_INTERVAL_MS until minute changes
    DEBUG_PRINT("Active polling (");
    DEBUG_PRINT(POLL_INTERVAL_MS);
    DEBUG_PRINTLN("ms) - waiting for minute change");
  }

  // Active polling mode - check every POLL_INTERVAL_MS
  // This catches the minute change quickly
  delay(POLL_INTERVAL_MS);
}

/**
 * Update e-paper display with current time from RTC
 */
void updateDisplay() {
  // Initialize display ONLY ONCE on first call
  if (!displayInitialized) {
    display.init(115200, true, 2, false);
    display.setRotation(0);
    displayInitialized = true;
  }

  // Get formatted time and date from RTC
  String timeStr = rtcManager.getFormattedTime(!currentWatchFace->noAMPM);
  String dateStr = rtcManager.getFormattedDate();
  uint8_t currentMinute = rtcManager.getCurrentMinute();

  // Check if it's time for full refresh (every 10 mins: :00, :10, :20, etc.)
  bool isFullRefreshTime = (currentMinute % FULL_REFRESH_INTERVAL == 0);

  // Cycle to random watchface if enabled and it's full refresh time
  if (ENABLE_WATCHFACE_CYCLING && isFullRefreshTime && !firstUpdate) {
    // Independent uniform draw each time, excluding only the face on screen now
    currentWatchFaceIndex = pickNextWatchFace(currentWatchFaceIndex);
    currentWatchFace = allWatchFaces[currentWatchFaceIndex];
    DEBUG_PRINT("Random watchface #");
    DEBUG_PRINT(currentWatchFaceIndex);
    DEBUG_PRINT(" (");
    DEBUG_PRINT(NUM_WATCHFACES);
    DEBUG_PRINTLN(" total)");
  }

  // Determine refresh mode
  // FULL refresh: First update OR every 10 minutes (for ghosting prevention)
  // PARTIAL refresh: All other times (faster, no flicker)
  bool usePartialRefresh = ENABLE_PARTIAL_REFRESH &&
                          !firstUpdate &&
                          !isFullRefreshTime;

  if (firstUpdate) {
    firstUpdate = false;
  }

  unsigned long startTime = millis();

  // Draw watchface
  drawWatchFace(currentWatchFace, timeStr, dateStr, usePartialRefresh);

  unsigned long elapsed = millis() - startTime;
  DEBUG_PRINT(timeStr);
  DEBUG_PRINT(" (");
  DEBUG_PRINT(usePartialRefresh ? "partial" : "full");
  DEBUG_PRINT(", ");
  DEBUG_PRINT(elapsed);
  DEBUG_PRINTLN("ms)");

  // Put display in low-power mode
  display.hibernate();
}

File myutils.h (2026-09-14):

#pragma once
#include <SPI.h>
#include <Wire.h>
#include <GxEPD2_BW.h>
#include <Adafruit_GFX.h>
#include <RTClib.h>
#include "bitmaps/Bitmaps200x200.h"

// E-Paper Display Pin Definitions (GoodDisplay 1.54" - GDEH0154D67)
#define EPD_MOSI  D10  // SPI MOSI - Hardware SPI (labelled DAT / DIN / SDA on breakouts)
#define EPD_SCK   D8   // SPI Clock - Hardware SPI (labelled SCL / CLK / SCK on breakouts)
#define EPD_CS    D1   // Chip Select (CS) - GPIO
#define EPD_DC    D3   // Data/Command (DC) - GPIO
#define EPD_RST   D0   // Reset (RES) - GPIO
#define EPD_BUSY  D9   // Busy Signal (BUSY) - GPIO. Wired but NOT used by the firmware (see myutils.cpp).
                       // Was D6; D6 is now buried under epoxy on the Xiao, so BUSY moved to D9.

// RTC (DS3231) Pin Definitions
// Using default hardware I2C pins (no Wire.begin(SDA,SCL) needed)
#define RTC_SDA           D4   // I2C SDA (Hardware I2C)
#define RTC_SCL           D5   // I2C SCL (Hardware I2C)
#define RTC_INTERRUPT_PIN D2   // SQW/INT alarm interrupt - GPIO

// Future: Button for time sync / menu navigation
#define BUTTON_PIN        D7   // User input (with internal pull-up) - GPIO

#include "WatchFace.h"
#include "RTCManager.h"

// include all fonts used, here
#include <Fonts/FreeMonoBold9pt7b.h>
#include "myfonts/CourierPrime_Bold10pt7b.h"
#include "myfonts/CourierPrime_Bold20pt7b.h"
#include "myfonts/StarJedi_DGRW10pt7b.h"
#include "myfonts/StarJedi_DGRW20pt7b.h"
#include "myfonts/DynaPuff_VariableFont_wdth_wght10pt7b.h"
#include "myfonts/DynaPuff_VariableFont_wdth_wght20pt7b.h"
#include "myfonts/Helloworld_ovvY040pt7b.h"
#include "myfonts/Helloworld_ovvY030pt7b.h"
#include "myfonts/Helloworld_ovvY020pt7b.h"
#include "myfonts/Helloworld_ovvY010pt7b.h"
#include "myfonts/BekingBold_1Gqdg20pt7b.h"
#include "myfonts/BekingBold_1Gqdg10pt7b.h"
#include "myfonts/OctoberTwilight_Ooe610pt7b.h"
#include "myfonts/OctoberTwilight_Ooe615pt7b.h"
#include "myfonts/ToughCookiesBold_owZ1d10pt7b.h"
#include "myfonts/ToughCookiesBold_owZ1d20pt7b.h"
#include "myfonts/ToughCookiesBold_owZ1d30pt7b.h"
#include "myfonts/ToughCookiesBold_owZ1d15pt7b.h"
#include "myfonts/Caveat_VariableFont_wght10pt7b.h"
#include "myfonts/Caveat_VariableFont_wght20pt7b.h"
#include "myfonts/Beyblade_Metal_Fight_Font20pt7b.h"
#include "myfonts/Beyblade_Metal_Fight_Font10pt7b.h"
#include "myfonts/Neuton_Bold20pt7b.h"
#include "myfonts/Neuton_Bold10pt7b.h"
#include "myfonts/BADABB__20pt7b.h"
#include "myfonts/BADABB__10pt7b.h"
#include "myfonts/CompactaBT20pt7b.h"
#include "myfonts/CompactaBT10pt7b.h"
#include "myfonts/HARRYP__20pt7b.h"
#include "myfonts/HARRYP__10pt7b.h"
#include "myfonts/Bumbastika_edited10pt7b.h"
#include "myfonts/Bumbastika_edited7pt7b.h"
#include "myfonts/Monster_AG20pt7b.h"
#include "myfonts/Monster_AG10pt7b.h"
#include "myfonts/Bootle_4B9l10pt7b.h"
#include "myfonts/Bootle_4B9l20pt7b.h"
#include "myfonts/Bootle_4B9l30pt7b.h"
#include "myfonts/PsBold_2Oy2w20pt7b.h"
#include "myfonts/PsBold_2Oy2w10pt7b.h"
#include "myfonts/Orbitron_Bold15pt7b.h"
#include "myfonts/Orbitron_Bold10pt7b.h"

// include all watchfaces used, here
#include "mywatchfaces/atat.h"
#include "mywatchfaces/atdp.h"
#include "mywatchfaces/b1.h"
#include "mywatchfaces/ben10.h"
#include "mywatchfaces/bird.h"
#include "mywatchfaces/bird2.h"
#include "mywatchfaces/bugs.h"
// #include "mywatchfaces/claw.h"
#include "mywatchfaces/claw2.h"
#include "mywatchfaces/claw3.h"
// #include "mywatchfaces/crow.h"
#include "mywatchfaces/dog.h"
// #include "mywatchfaces/giraffe1.h"
#include "mywatchfaces/guitar1.h"
#include "mywatchfaces/guitar2.h"
#include "mywatchfaces/h.h"
#include "mywatchfaces/harley.h"
#include "mywatchfaces/harry934.h"
#include "mywatchfaces/herbert.h"
#include "mywatchfaces/hogwarts.h"
#include "mywatchfaces/hogwarts2.h"
#include "mywatchfaces/hogwarts3.h"
#include "mywatchfaces/hogwarts4.h"
#include "mywatchfaces/jitsu1.h"
#include "mywatchfaces/jitsu2.h"
#include "mywatchfaces/jitsu3.h"
#include "mywatchfaces/jitsu4.h"
#include "mywatchfaces/jitsu5.h"
#include "mywatchfaces/krishna.h"
#include "mywatchfaces/macaw.h"
#include "mywatchfaces/mikew.h"
#include "mywatchfaces/mountain1.h"
#include "mywatchfaces/mountain2.h"
#include "mywatchfaces/peacock.h"
#include "mywatchfaces/peacock3.h"
#include "mywatchfaces/pegasus.h"
#include "mywatchfaces/penguin_beatles.h"
#include "mywatchfaces/penguins.h"
#include "mywatchfaces/planets.h"
#include "mywatchfaces/ps.h"
#include "mywatchfaces/saturn.h"
#include "mywatchfaces/sensei.h"
#include "mywatchfaces/sortinghat.h"
#include "mywatchfaces/stormtrooper2.h"
#include "mywatchfaces/stormtrooper3_floyd.h"
#include "mywatchfaces/sullivan.h"
#include "mywatchfaces/thiruman.h"
#include "mywatchfaces/tom.h"
#include "mywatchfaces/tree.h"
#include "mywatchfaces/walker.h"
#include "mywatchfaces/xwing.h"
#include "mywatchfaces/zebra.h"
// generated by watchfaceutils/generate_geometric.py
#include "mywatchfaces/tie.h"
#include "mywatchfaces/deathstar.h"
#include "mywatchfaces/hallows.h"
#include "mywatchfaces/prism.h"
#include "mywatchfaces/orbit.h"
#include "mywatchfaces/orion.h"
#include "mywatchfaces/kolam.h"
#include "mywatchfaces/vinyl.h"
#include "mywatchfaces/sunburst.h"
#include "mywatchfaces/minimal.h"
#include "mywatchfaces/moon.h"
#include "mywatchfaces/glasses.h"
#include "mywatchfaces/snitch.h"
#include "mywatchfaces/lightsaber.h"
#include "mywatchfaces/rocket.h"
#include "mywatchfaces/cassette.h"
#include "mywatchfaces/equalizer.h"
#include "mywatchfaces/mandala.h"
#include "mywatchfaces/forest.h"
#include "mywatchfaces/dial.h"
#include "mywatchfaces/waves.h"
#include "mywatchfaces/r2d2.h"
#include "mywatchfaces/falcon.h"
#include "mywatchfaces/hedwig.h"
#include "mywatchfaces/penguin.h"
#include "mywatchfaces/headphones.h"
#include "mywatchfaces/ufo.h"
#include "mywatchfaces/balloon.h"
#include "mywatchfaces/lighthouse.h"
#include "mywatchfaces/diya.h"
#include "mywatchfaces/coffee.h"
#include "mywatchfaces/bicycle.h"
#include "mywatchfaces/whale.h"
#include "mywatchfaces/thunderjaw.h"
#include "mywatchfaces/watcher.h"
#include "mywatchfaces/sawtooth.h"
#include "mywatchfaces/stormbird.h"
#include "mywatchfaces/strider.h"
#include "mywatchfaces/vader.h"
#include "mywatchfaces/mando.h"
#include "mywatchfaces/boodoor.h"
#include "mywatchfaces/astronaut.h"
#include "mywatchfaces/cat.h"
#include "mywatchfaces/camera.h"
#include "mywatchfaces/sailboat.h"
#include "mywatchfaces/hari.h"


extern GxEPD2_BW<GxEPD2_154_D67, GxEPD2_154_D67::HEIGHT> display;

void drawWatchFace(
  const WatchFace* face,
  String text1,  // time
  String text2,  // date
  bool partialRefresh
);

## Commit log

2025-07-05 Add framework for WatchFace configuration/customization
2025-10-21 Deep sleep to save battery; poll after though
2025-11-27 Add 3D printables
    [lid.skp, lid.stl, mainbox.skp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]
2026-09-13 Retire watchfaces: squares, squares_invert, claw, crow, giraffe1
    squares/squares_invert are deleted outright (their structs were named
    WatchFace_square*, which the array still referenced). claw, crow and
    giraffe1 are commented out but kept on disk.
2026-09-13 Pick watchfaces with the nRF52840 hardware RNG
    Each change event is now an independent uniform draw from the chip's
    thermal-noise RNG peripheral (bias correction on, rejection sampling so
    there is no modulo bias), excluding only the face currently on screen.
    Replaces the RTC-seeded LCG sequence. A shuffle-bag was evaluated and
    rejected in favour of true independence; see RANDOMNESS_ANALYSIS.md.
    [graytimer.ino]
2026-09-14 Add 27 generated watchfaces (clip art, Horizon Zero Dawn, Star Wars helmets) plus gallery and font tooling
    Clip art (drawn by watchfaceutils/generate_geometric.py): r2d2, falcon,
    hedwig, penguin, headphones, ufo, balloon, lighthouse, diya, coffee,
    bicycle, whale, boodoor, astronaut, cat, camera, sailboat, and hari
    (Tamil script from the system Tamil MN font).
    Horizon Zero Dawn: thunderjaw, watcher, sawtooth, stormbird, strider from
    Horizon Wiki renders (alpha outline + thresholded shading, 1-bit sources in
    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
2026-09-14 Document BUSY on D9, breakout pin aliases, and the display repair log
    - BUSY moves from D6 (now under epoxy) to D9; firmware still passes -1
    - Pin tables list the DAT/DIN/SDA and SCL/CLK/SCK label aliases
    - Add hardware/epd_test standalone diagnostic sketch (BUSY monitored,
    library diagnostics on, continuous refresh for probing boost rails)
    - Repair log in docs/HARDWARE.md: findings from the post-short teardown and
    the Waveshare 1.54" V2 replacement plan
    - Document the serial time-setting format next to ENABLE_TIME_SETUP
    [graytimer.ino, myutils.h]
